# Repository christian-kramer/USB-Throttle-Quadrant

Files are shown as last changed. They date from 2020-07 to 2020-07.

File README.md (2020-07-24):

# USB-Throttle-Quadrant
Designing Open-Source Flight Sim Hardware
___

I'm an avid flight simulator enthusiast. For as long as I can remember, I've been flying planes on the PC... everything from single-engine Cessnas, rotorcraft, fighter aircraft, and the largest of passenger airliners. Unfortunately, my options for *controlling* these aircraft have always been marginal at best.

My first joystick was a Microsoft Sidewinder Standard joystick from 1995. Coupled with Microsoft Flight Simulator 98, it proved to be loads of fun for 5-year-old me.

Sidewinder Standard

Unfortunately, at the time, I couldn't figure out how to make the throttle wheels on either side of the joystick work, so I had to resort to adjusting engine power with the keyboard function keys. Needless to say this made landing difficult (or impossible for a 5-year-old) and there was virtually no hope that any aircraft I piloted would ever come down in one piece.

My next joystick was a Logitech Extreme 3D Pro. This thing was amazing compared to the Sidewinder! It was USB, had what seemed like infinite buttons, and... a working throttle!

Extreme 3D Pro

I loved this thing so much. Coupled with Microsoft Flight Simulator 2000, landing was not only possible... it was sometimes survivable! Buzzing around Chicago in a British Airways Concorde was so much fun. I could control my view, put on the brakes, even lower the landing gear without even lifting my hand from the stick! But it just wasn't enough.

After upgrading to X-Plane 9, I realized there was a whole world of realism and types of aircraft out there for me to explore. Starting engines, lowering flaps, deploying speedbrakes, transitioning to forward flight in VTOL aircraft, all required levels of control I just couldn't get with my trusty old logitech joystick. Enter, the Thrustmaster T. Flight Stick X

T Flight

This is actually my current joystick, as of writing this. The ergonomics are far superior to the Logitech, allowing much more precise approaches. I can trim my aircraft very easily with the 6-way hat switch, and just as easily dump my trim with the other buttons on the control stick. Flaps, speedbrakes, reverse thrust, engine start, and view are all mapped to the buttons on the base. The throttle works, don't get me wrong... but there's an annoying clicky detent when you cross between the red and white zones that really inhibits smooth movement. Additionally, with only one throttle lever,  I can't use variable thrust in multi-engine aircraft. This is annoying when making tight turns in a King Air C90 or Boeing 737. I needed... more.

Throttle Quadrant

But $60 seems a bit steep for 3 wimpy throttle axis! I want something meatier, like what you find in an airliner.

Expensive Throttle Quadrant

Holy cow! I wanted something that you would find ***in*** an airliner, not something that costs as much ***as*** an airliner!

I should just make my own at that point.

And, so, I decided I would! I had an idea in my head of what I wanted. Two independent throttles, with spring-loaded reverse-thrust that would engage when you pulled them back past idle. That way, when you "hold" the aircraft in reverse to slow down, you could return the engines to idle by just letting go. Simple!

Spending some time at the computer led me to come up with this design:

[Animation](https://i.imgur.com/kygk9N8.mp4)

Which I was able to almost entirely 3D print, save for the skateboard bearings, screws, and potentiometers.

First Rev

Unfortunately, 3D printing isn't perfect, and neither was my design. The screws that were supposed to follow the "tracks" on either side kept coming out, and very quickly wore out the plastic from the friction.

Worn out

I needed a much more robust design if I wanted this to feel anywhere close to usable. I started looking at different springs I could use that offered more resistance than my tiny extension springs.

Eventually, I came across this avenue on Amazon:

RC Shocks

RC Car shock absorbers! They're the perfect size, look like little gas cylinders, and have bearings built in on either end! 33mm of travel is plenty for my needs, so I decided to pull the trigger and see if they'd work.

After they arrived, I set to work designing an extremely accurate 3D representation of them to use in my design process.

3D Shocks

Next, I modified my first throttle design to incorporate these shocks. I ended up going with this:

[Animation](https://i.imgur.com/Ubx0nK9.mp4)

For this project, I decided to forego designing a custom PCB and to try using what I had lying around instead. A Universal PCB was perfect for mounting the potentiometers to, and a Blue Pill was perfect for the main brain.

PCB

Interior PCB

The cool part was that the cylinders and the secondary bearings for the  "arm" were all contained within the throttle's housing, so I was able to retain the single-bearing look from the outside.

Interior 1

Interior 2

Exterior 1

Pretty clean look from the outside, if you ask me!

After putting it together, I started writing the firmware for the STM32F103C8T6. By now, I've gotten pretty familiar with USB descriptors and the STM32's USB peripheral. Specifying 4 joystick axis, however, was more difficult than I figured it should be. Initially, I defined four distinct axis of the "throttle" class (two for throttle, two for reverse thrust) compliant with the USB Human Interface Device Descriptor spec. But when I plugged it in to my PC, Windows only recognized 3 of the 4 throttle axis! I double-checked my descriptor, and sure enough, everything looked fine. Windows was just ignoring one of my throttles. My immediate question was "okay, which one is it ignoring?" So I re-classified the 4 throttles to different things like "accelerator, clutch, brake, and steering". Interestingly enough, the "brake" axis was missing when I plugged it back in to my PC! "Why is Windows just totally ignoring the third axis?!" After playing around some more, I discovered that it wasn't always the third axis it ignored. As far as I could tell, there was no rhyme or reason as to which of the 4 axis Windows chose to ignore. It appears to me that Windows was only capable of recognizing up to 3 axis that are part of a "simulation controls" usage page. It's possible that there's a fundamental flaw in how I was describing these axis to Windows, but I was able to confirm that using 4 (mostly) arbitrary generic joystick axis names like "Z, X (rot), Y (rot), and Z (rot)" appeared in Windows just fine. Ultimately, how these axis are presented to the operating system is of little consequence; I just cared about assigning all 4 of them to the appropriate functions in X-Plane.

Something to note at this point is how I was able to use two potentimeters to control 4 separate joystick axis. On each lever, there are 3 defined "detents": Maximum Thrust, Idle Thrust, and Maximum Reverse Thrust. Since Idle Thrust is always a known number of degrees "behind" Maximum Thrust, using Maximum Thrust as a reference point I could determine in my firmware when I was going to feel the Idle Thrust position detent as I pulled the levers back. The moment I pulled the levers back *beyond* idle thrust, then the firmware could increase the Reverse Thrust amount for that particular lever. Maximum Reverse Thrust is always a known number of degrees "beyond" Idle Thrust, so it was very straightforward to determine the value for that axis.

Ultimately, I ended up with a pretty great homebuilt peripheral for the bulk of my flight simulator aircraft.

Here's a video of me using the finished unit to land a Boeing 737-800 at Boston Logan International Airport:

[Video](https://i.imgur.com/aLXppK2.mp4)

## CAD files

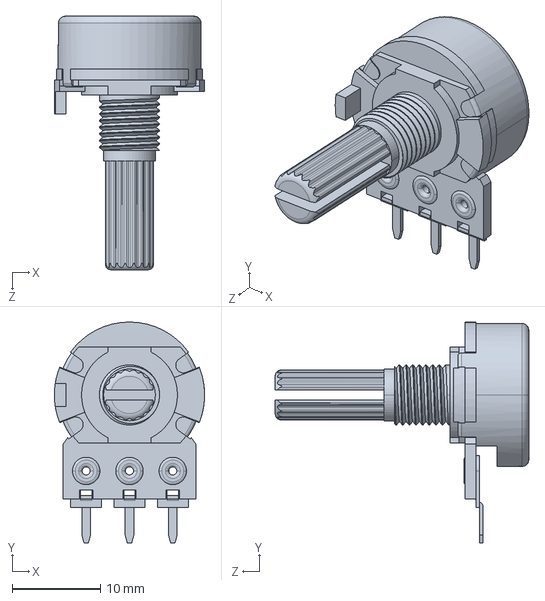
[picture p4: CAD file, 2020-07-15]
Mechanical/CAD Parts/Potentiometer/Potentiometer.STEP
17.0 x 25.0 x 28.7 mm

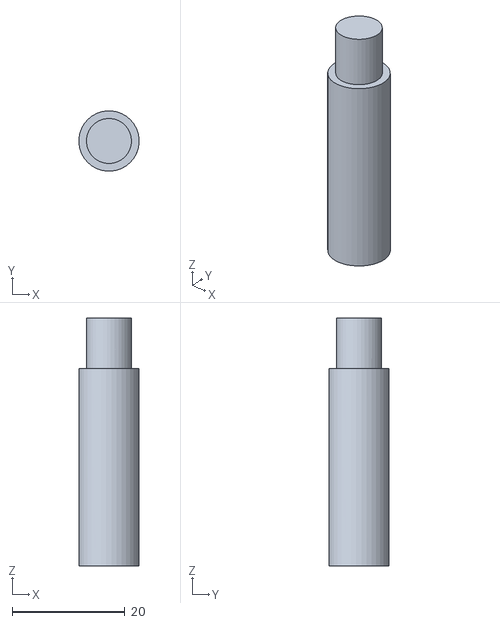
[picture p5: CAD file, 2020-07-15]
Mechanical/Test Parts/HandleAxleTest.stl
10.7 x 10.7 x 44.0

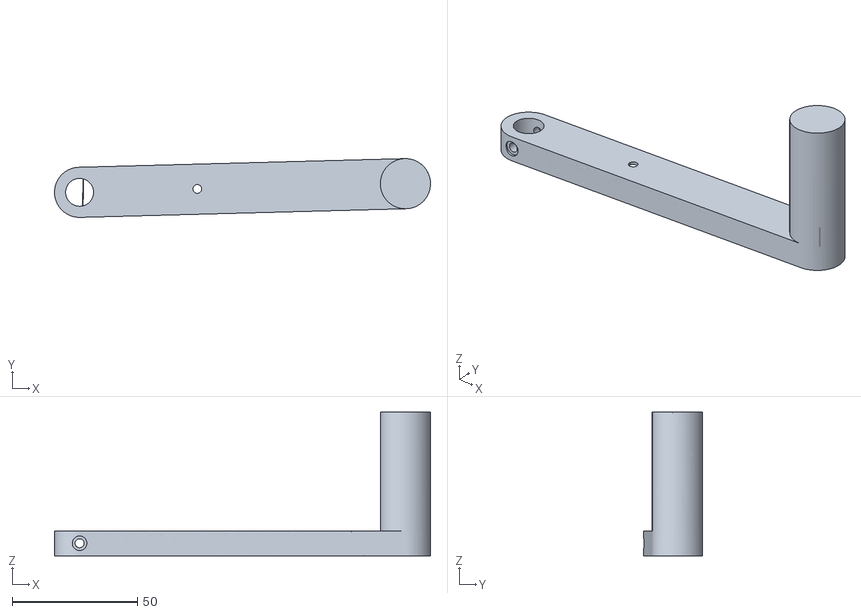
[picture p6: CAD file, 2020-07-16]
Mechanical/To Print/Revision 2/Left Handle.stl
150.0 x 23.4 x 57.4

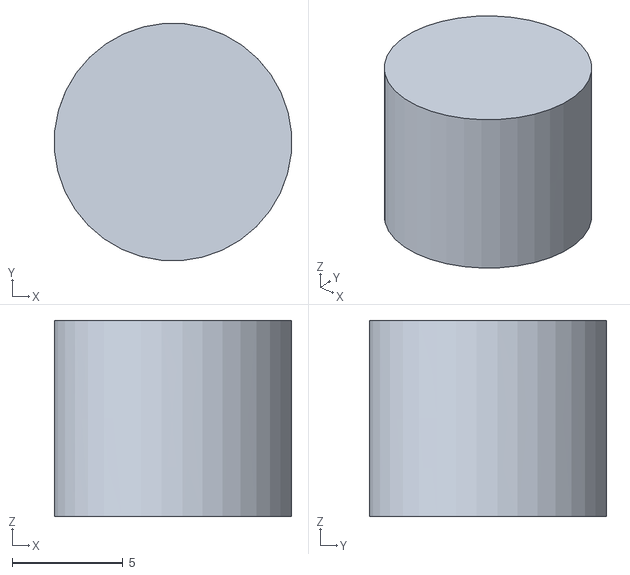
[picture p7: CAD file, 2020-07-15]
Mechanical/Test Parts/PLAPlusPotTest2.stl
10.7 x 10.7 x 8.86

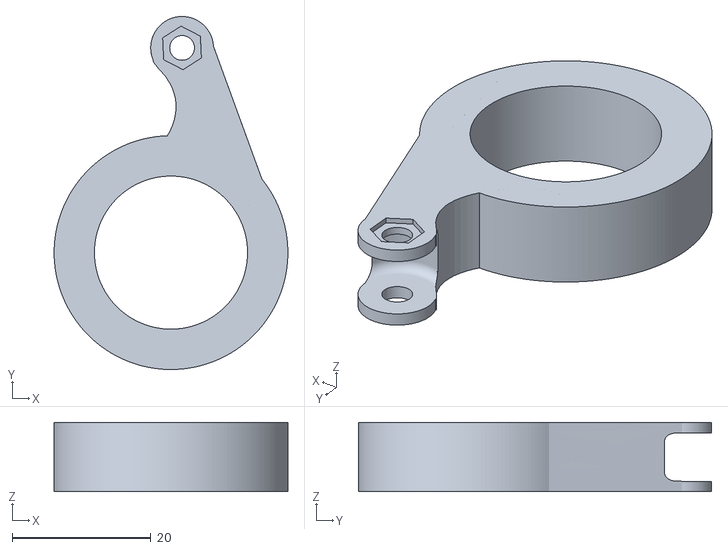
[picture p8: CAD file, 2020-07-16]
Mechanical/To Print/Revision 2/Shock Bearing.stl
33.7 x 51.0 x 10.0

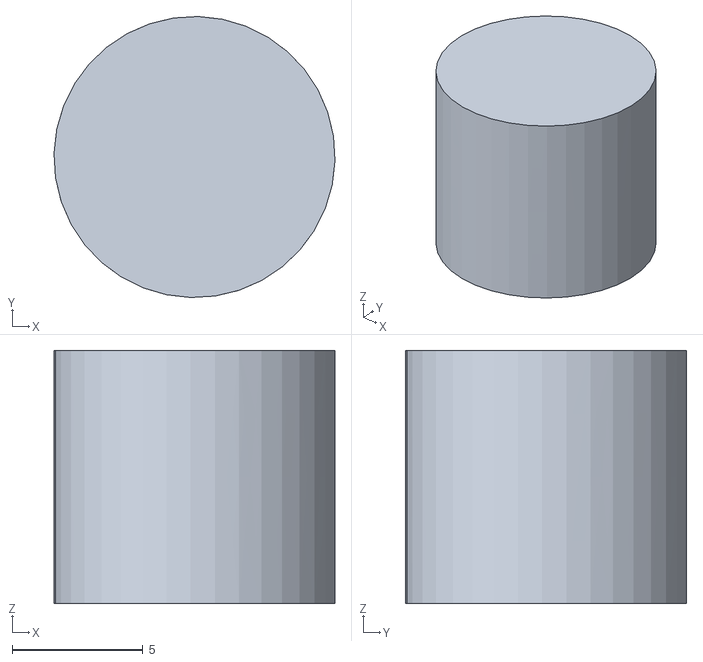
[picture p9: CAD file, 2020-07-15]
Mechanical/Test Parts/PLAPlusPotTest.stl
10.7 x 10.7 x 9.68

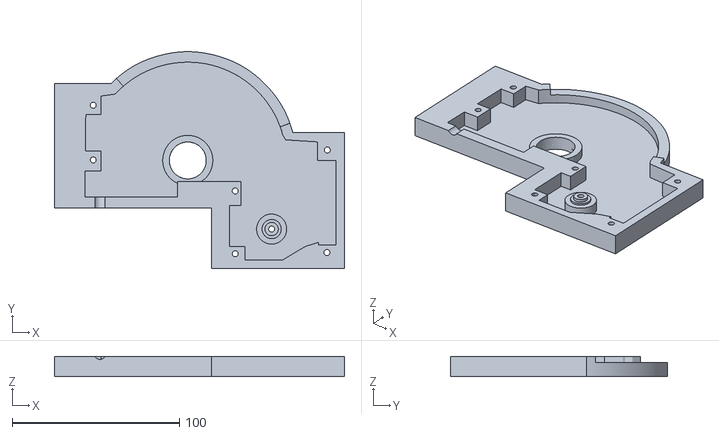
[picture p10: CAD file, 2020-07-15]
Mechanical/To Print/Revision 2/Right Side.stl
173.5 x 129.7 x 12.0

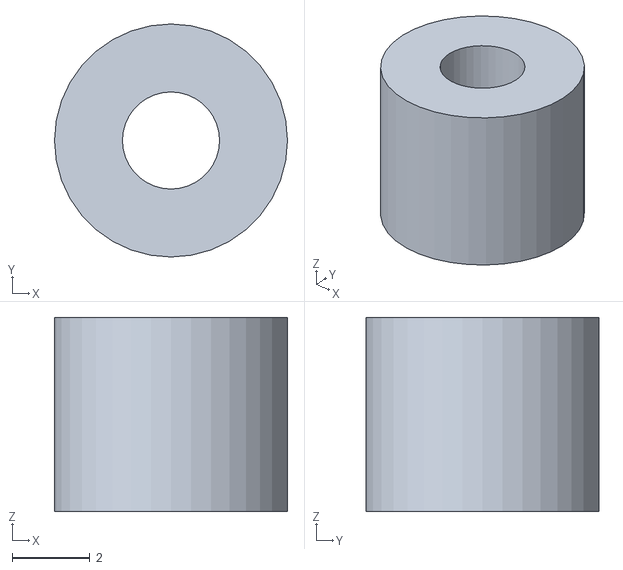
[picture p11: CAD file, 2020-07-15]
Mechanical/Test Parts/Board Mount Side.stl
6.00 x 6.00 x 5.00

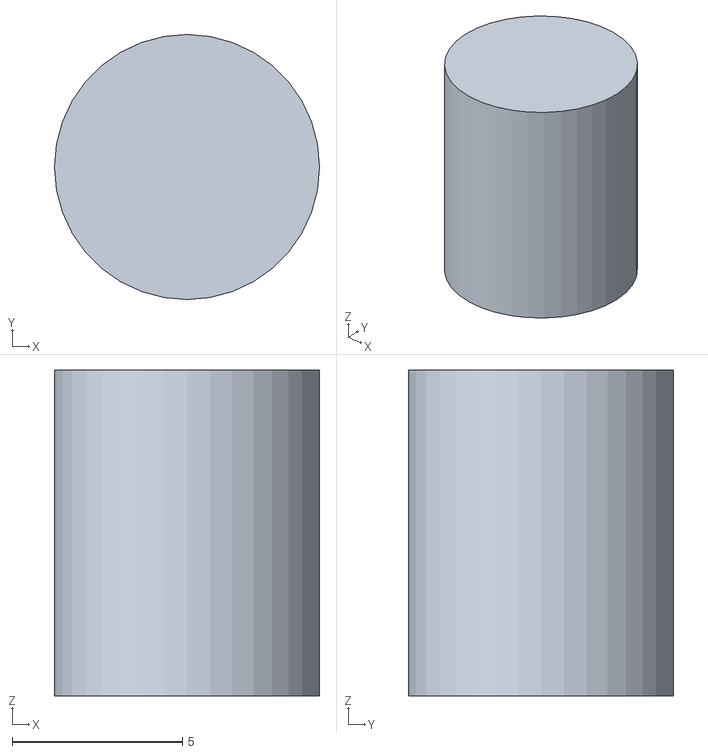
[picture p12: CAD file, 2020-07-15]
Mechanical/Test Parts/Bearing Inner.stl
7.80 x 7.80 x 9.59

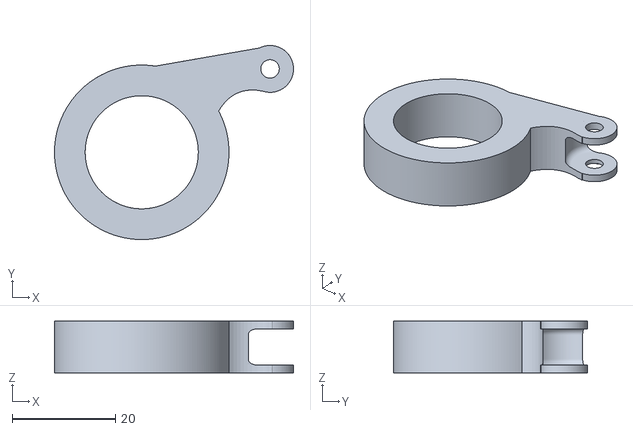
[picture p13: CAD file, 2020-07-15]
Mechanical/Test Parts/ShockBearingTest2.stl
46.2 x 37.5 x 10.0

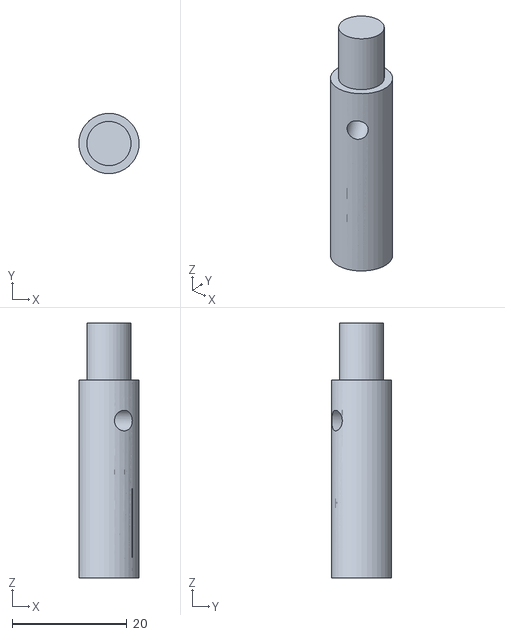
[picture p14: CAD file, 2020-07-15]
Mechanical/To Print/Revision 2/Right Axle.stl
10.5 x 10.5 x 44.4

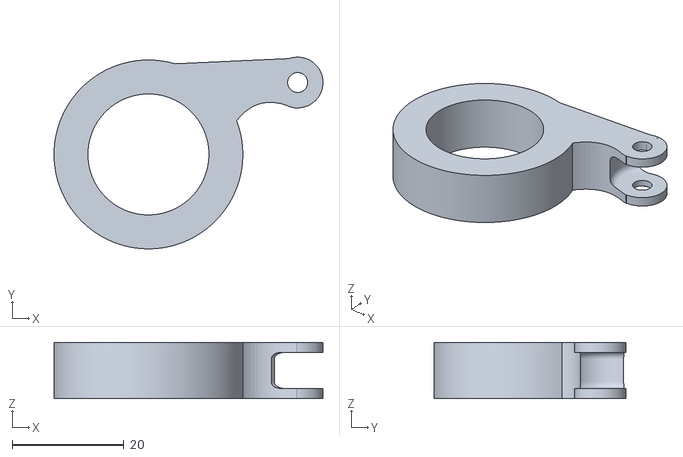
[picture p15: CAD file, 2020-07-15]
Mechanical/Test Parts/ShockBearingTest.stl
48.1 x 34.3 x 10.0

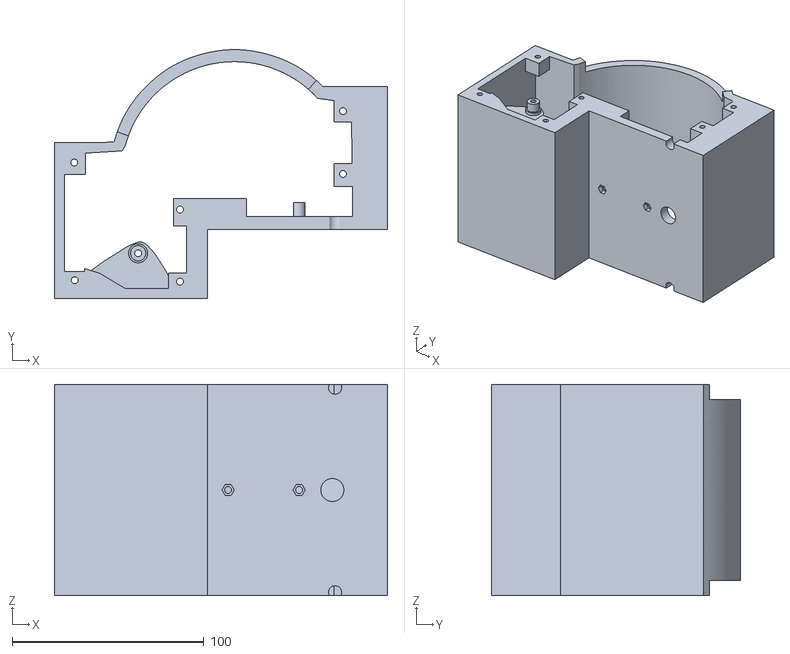
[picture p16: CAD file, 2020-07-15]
Mechanical/To Print/Revision 2/Middle Body.stl
173.6 x 129.7 x 110.0

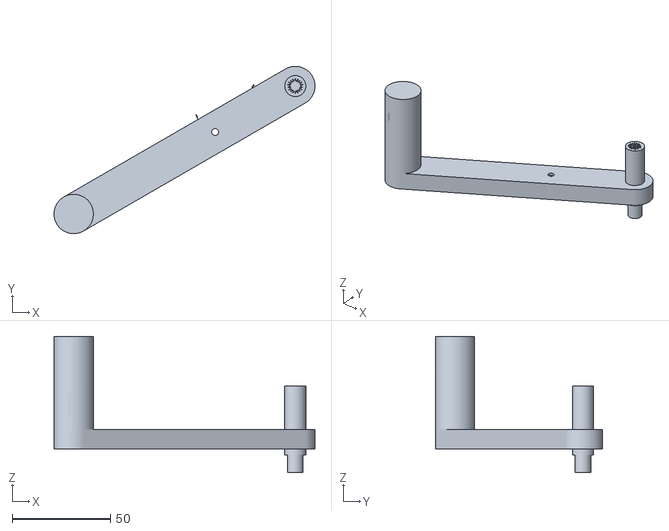
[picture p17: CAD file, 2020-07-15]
Mechanical/Test Parts/RightHandle.stl
132.6 x 85.0 x 69.3

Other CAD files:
Mechanical/CAD Parts/Potentiometer/Potentiometer-W-Color.STEP
Mechanical/To Print/Revision 2/Right Handle.stl
Mechanical/To Print/Revision 2/Left Side.stl
Mechanical/Test Parts/Bearing Outer.stl
Mechanical/CAD Parts/Potentiometer/Potentiometer.IGS
Mechanical/CAD Parts/Potentiometer/Potentiometer.SLDPRT
Mechanical/CAD Parts/Potentiometer/Potentiometer.STL
Mechanical/Test Parts/ShockBearingTest2.obj
Mechanical/Test Parts/ShockBearingTest3.stl
Mechanical/To Print/Revision 1/Body.stl
Mechanical/To Print/Revision 1/Left Handle Bottom.stl
Mechanical/To Print/Revision 1/Left Handle Top.stl
Mechanical/To Print/Revision 1/Pot Axle Test.stl
Mechanical/To Print/Revision 1/Right Handle Bottom.stl
Mechanical/To Print/Revision 1/Right Handle Top.stl
Mechanical/To Print/Revision 1/Side 1.stl
Mechanical/To Print/Revision 1/Side 2.stl
Mechanical/To Print/Revision 1/Sides.stl

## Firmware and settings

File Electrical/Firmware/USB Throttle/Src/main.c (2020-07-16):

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

/* Includes ------------------------------------------------------------------*/
#include "main.h"
#include "usb_device.h"

/* USER CODE BEGIN Includes */
#include "stdbool.h"
#include "stdint.h"
#include "math.h"
#include "usbd_custom_hid_if.h"
extern USBD_HandleTypeDef hUsbDeviceFS;
/* USER CODE END Includes */

/* USER CODE BEGIN PD */
#define SAMPLE_DURATION 5000
/* USER CODE END PD */

ADC_HandleTypeDef hadc1;
DMA_HandleTypeDef hdma_adc1;

/* USER CODE BEGIN PV */

uint32_t last_time;
bool calibrated = false;

/* USER CODE END PV */

void SystemClock_Config(void);
static void MX_GPIO_Init(void);
static void MX_DMA_Init(void);
static void MX_ADC1_Init(void);
/* USER CODE BEGIN 0 */
uint8_t adc_to_percent(uint16_t adc_value)
{
	return round((adc_value / 4095.0) * 100);
}
/* USER CODE END 0 */

/**
  * @brief  The application entry point.
  * @retval int
  */
int main(void)
{
  /* USER CODE BEGIN 1 */

  uint32_t adcBuffer[2];

  /* USER CODE END 1 */
  

  /* MCU Configuration--------------------------------------------------------*/

  /* Reset of all peripherals, Initializes the Flash interface and the Systick. */
  HAL_Init();

  /* Configure the system clock */
  SystemClock_Config();

  /* Initialize all configured peripherals */
  MX_GPIO_Init();
  MX_USB_DEVICE_Init();
  MX_DMA_Init();
  MX_ADC1_Init();
  /* USER CODE BEGIN 2 */

  struct throttle_report_t
  {
	  uint16_t throttle1;
	  uint16_t throttle2;
	  uint16_t reverser1;
	  uint16_t reverser2;
  };

  HAL_ADC_Start_DMA(&hadc1, adcBuffer, 2);
  uint8_t max_percent[2];
  uint8_t idle_percent[2];
  uint16_t idle_value[2];

  last_time = HAL_GetTick();

  /* USER CODE END 2 */

  /* Infinite loop */
  /* USER CODE BEGIN WHILE */
  while (1)
  {
	  if (calibrated)
	  {
		  //this should be where the while looop ends up after calibrated

		  //top value is 53, bottom is 21...

		  struct throttle_report_t throttleReport;

		  throttleReport.throttle1 = (((adc_to_percent(adcBuffer[0]) - (max_percent[0] - 21)) / 22.0)) * 4095;
		  throttleReport.throttle2 = (((adc_to_percent(adcBuffer[1]) - (max_percent[1] - 22)) / 22.0)) * 4095;
		  throttleReport.reverser1 = ((((max_percent[0] - 22) - (adc_to_percent(adcBuffer[0]))) / 12.0)) * 4095;
		  throttleReport.reverser2 = ((((max_percent[1] - 22) - (adc_to_percent(adcBuffer[1]))) / 12.0)) * 4095;

		  USBD_CUSTOM_HID_SendReport(&hUsbDeviceFS, &throttleReport, sizeof(struct throttle_report_t));
	  }
	  else
	  {
		  if (HAL_GetTick() - last_time > SAMPLE_DURATION)
		  {
			  last_time = HAL_GetTick();
			  calibrated = true;
			  for (uint8_t i = 0; i < 2; i++)
			  {
				  idle_percent[i] = max_percent[i] - 22;
				  idle_value[i] = ((idle_percent[i] / 100.0) * 4095);
			  }
		  }
		  else
		  {
			  //this should be where the while loop ends up before calibrated
			  for (uint8_t i = 0; i < 2; i++)
			  {
				  uint8_t current_percent = adc_to_percent(adcBuffer[i]);
				  if ((max_percent[i] < current_percent) && (current_percent <= 100))
				  {
					  max_percent[i] = current_percent;
				  }
			  }
		  }
	  }


    /* USER CODE END WHILE */

    /* USER CODE BEGIN 3 */
  }
  /* USER CODE END 3 */
}

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


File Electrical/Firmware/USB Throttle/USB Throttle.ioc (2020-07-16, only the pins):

Mcu.UserName=STM32F103C8Tx
PA11.Signal=USB_DM
PA12.Signal=USB_DP
PA13.Signal=SYS_JTMS-SWDIO
PA14.Signal=SYS_JTCK-SWCLK
PB0.Signal=ADCx_IN8
PB1.Signal=ADCx_IN9
PC13-TAMPER-RTC.Signal=GPIO_Output
PD0-OSC_IN.Signal=RCC_OSC_IN
PD1-OSC_OUT.Signal=RCC_OSC_OUT

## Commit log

2020-07-15 3d files for mechanical design
    [Bearing Inner.stl, Bearing Outer.stl, Board Mount Side.stl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]
2020-07-15 implemented descriptor with raw 2-chan. ADC output
2020-07-15 added calibration
2020-07-16 Added left side components
    [Left Handle.stl, Shock Bearing.stl]
2020-07-16 both throttles functional
2020-07-16 slight difference in calibration
2020-07-16 device renaming and change of L throttle authority

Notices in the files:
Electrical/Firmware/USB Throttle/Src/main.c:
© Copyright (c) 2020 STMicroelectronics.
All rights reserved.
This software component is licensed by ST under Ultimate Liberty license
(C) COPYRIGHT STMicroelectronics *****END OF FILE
